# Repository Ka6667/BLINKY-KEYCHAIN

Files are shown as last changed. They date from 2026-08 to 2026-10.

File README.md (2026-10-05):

Add a heading

## Table of Contents
* [What is BLINKY KEYCHAIN?](#what-is-blinky-keychain)
* [Why did I build it?](#why-did-i-build-it)
* [How to use BLINKY](#how-to-use-blinky)
* [How to build BLINKY](#how-to-build-blinky)
* [Schematics](#schematics)
* [PCB Design](#pcb-design)
* [BOM](#bom)

## What is BLINKY KEYCHAIN??
Blinky Keycahin is a custom made PCB that works as a keychain. it's so interactive and it looks really cool with built in modes for the LEDs. it also tells you the time in the OLED display. it's so small and so easy to assymble.

## Why did I build it?
This project is made for a friend. This friend always like to buy matching key chains so I decided to make one for both of us. The process of building was quite simple. I made the schematics using Kicad then I made the PCB. then I made a very simple zine page.

## How to use BLINKY?
the LEDS always keep making these cool patterns and the OLED Display shows the time to make sure that you will not get late to any appointment!

## How to build BLINKY?
1. First install the Gerber files and use JLCPCB to build the PCB.
2. Buy the rest of the components and use a soldering iron to solder everything.
3. Upload the code
4. ENJOY IT!!!!

## Schematics


## PCB Design




## BOM
| Part | Amount | Price | Link |
| :--- | :---: | :---: | :--- |
| XIAO-ESP32C3 | 1 | $3.9 | [Temu Link]([https://temu.com/ul/kuiper/un9.html](https://www.seeedstudio.com/XIAO-RP2040-v1-0-p-5026.html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)) |
| 1000K Ohm resistor | 1 | $0.05 | [Amazon Link](https://www.amazon.eg/-/en/Resistor-1K-ohm-4W-2pcs/dp/B0CJQ3M5J1/) |
| Push-buttons | 1 | $0.04 | [Temu Link](https://www.temu.com/eg-en/10pcs-6x6x5mm--tactile-tact-push-button-micro-switch-mini-micro-momentary-tactile-push-button-switch--x-5mm-g-605681855863393.html) |
| PCB | 1 | $2.00 | [JLCPCB Link](https://cart.jlcpcb.com) |
| LED | 5 | $0.20 | [LED](https://www.ram-e-shop.com/shop/led-pack-jumbo-300-led-pack-jumbo-mixed-300-led-free-storage-box-7525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) |
| LIPO-Battery | 1 | $1.10 | [Makers Electronics Link](https://makerselectronics.com/product/rechargeable-400925-lipo-battery/) |
| **Total** | | **$7.3** <br>*(shipping not included)* | |

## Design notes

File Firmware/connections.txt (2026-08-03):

LED
D0  
D1
D2
D3
D6
-------------------------
OLED
SDA = D4
SCL = D5
-------------------------
Libraries included!!! 
#include <Wire.h>
#include <Adafruit_GFX.h>
#include <Adafruit_SSD1306.h>
#include <RTClib.h>

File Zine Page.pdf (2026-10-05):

# BLINKY KEYCHAIN!

# MORE THAN A NORMAL KEYCHAIN

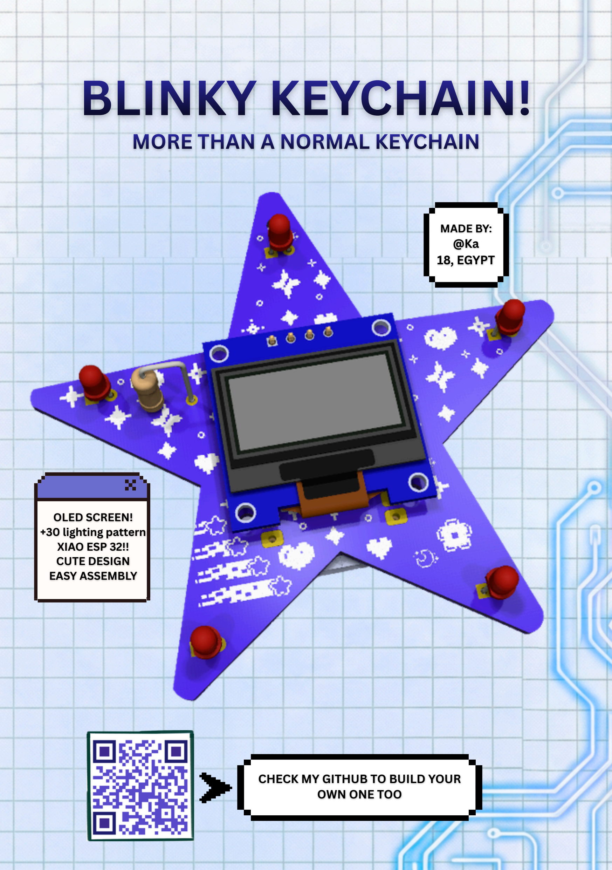
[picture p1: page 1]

CHECK MY GITHUB TO BUILD YOUR OWN ONE TOO

CHECK MY GITHUB TO BUILD YOUR OWN ONE TOO

MADE BY:
@Ka
18, EGYPT

MADE BY:
@Ka
18, EGYPT

OLED SCREEN!
+30 lighting pattern
XIAO ESP 32!!
CUTE DESIGN
EASY ASSEMBLY

OLED SCREEN!
+30 lighting pattern
XIAO ESP 32!!
CUTE DESIGN
EASY ASSEMBLY

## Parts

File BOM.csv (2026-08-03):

Part | Amount | Price | Link
XIAO-ESP32C3 | 1 | $3.90 | https://www.seeedstudio.com/XIAO-RP2040-v1-0-p-5026.html
1000K Ohm resistor | 1 | $0.05 | https://www.amazon.eg/-/en/Resistor-1K-ohm-4W-2pcs/dp/B0CJQ3M5J1/
Push-buttons | 1 | $0.04 | https://www.temu.com/eg-en/10pcs-6x6x5mm--tactile-tact-push-button-micro-switch-mini-micro-momentary-tactile-push-button-switch--x-5mm-g-605681855863393.html
PCB | 1 | $2.00 | https://cart.jlcpcb.com
LED | 5 | $0.20 | https://www.ram-e-shop.com/shop/led-pack-jumbo-300-led-pack-jumbo-mixed-300-led-free-storage-box-7525
LIPO-Battery | 1 | $1.10 | https://makerselectronics.com/product/rechargeable-400925-lipo-battery/
Total |  | $7.30 (shipping not included)

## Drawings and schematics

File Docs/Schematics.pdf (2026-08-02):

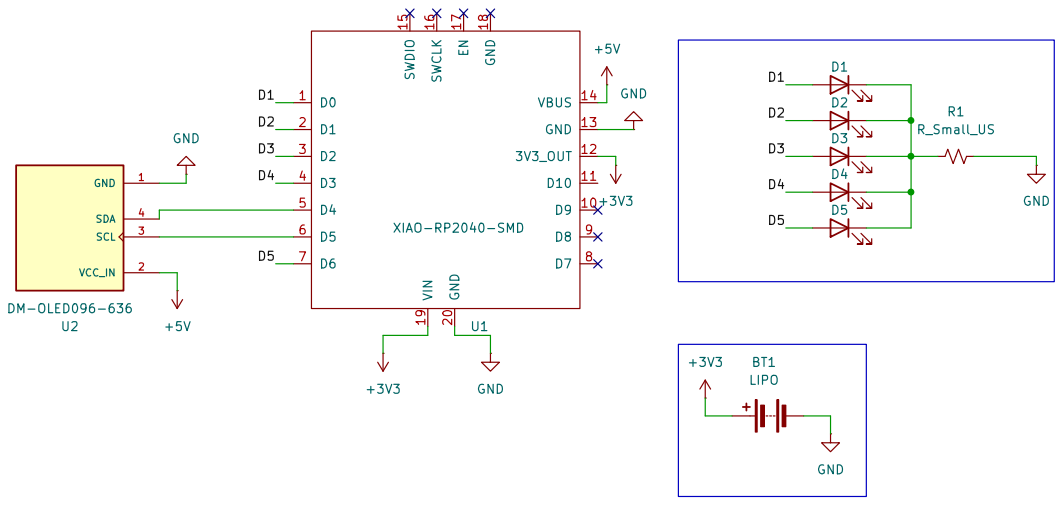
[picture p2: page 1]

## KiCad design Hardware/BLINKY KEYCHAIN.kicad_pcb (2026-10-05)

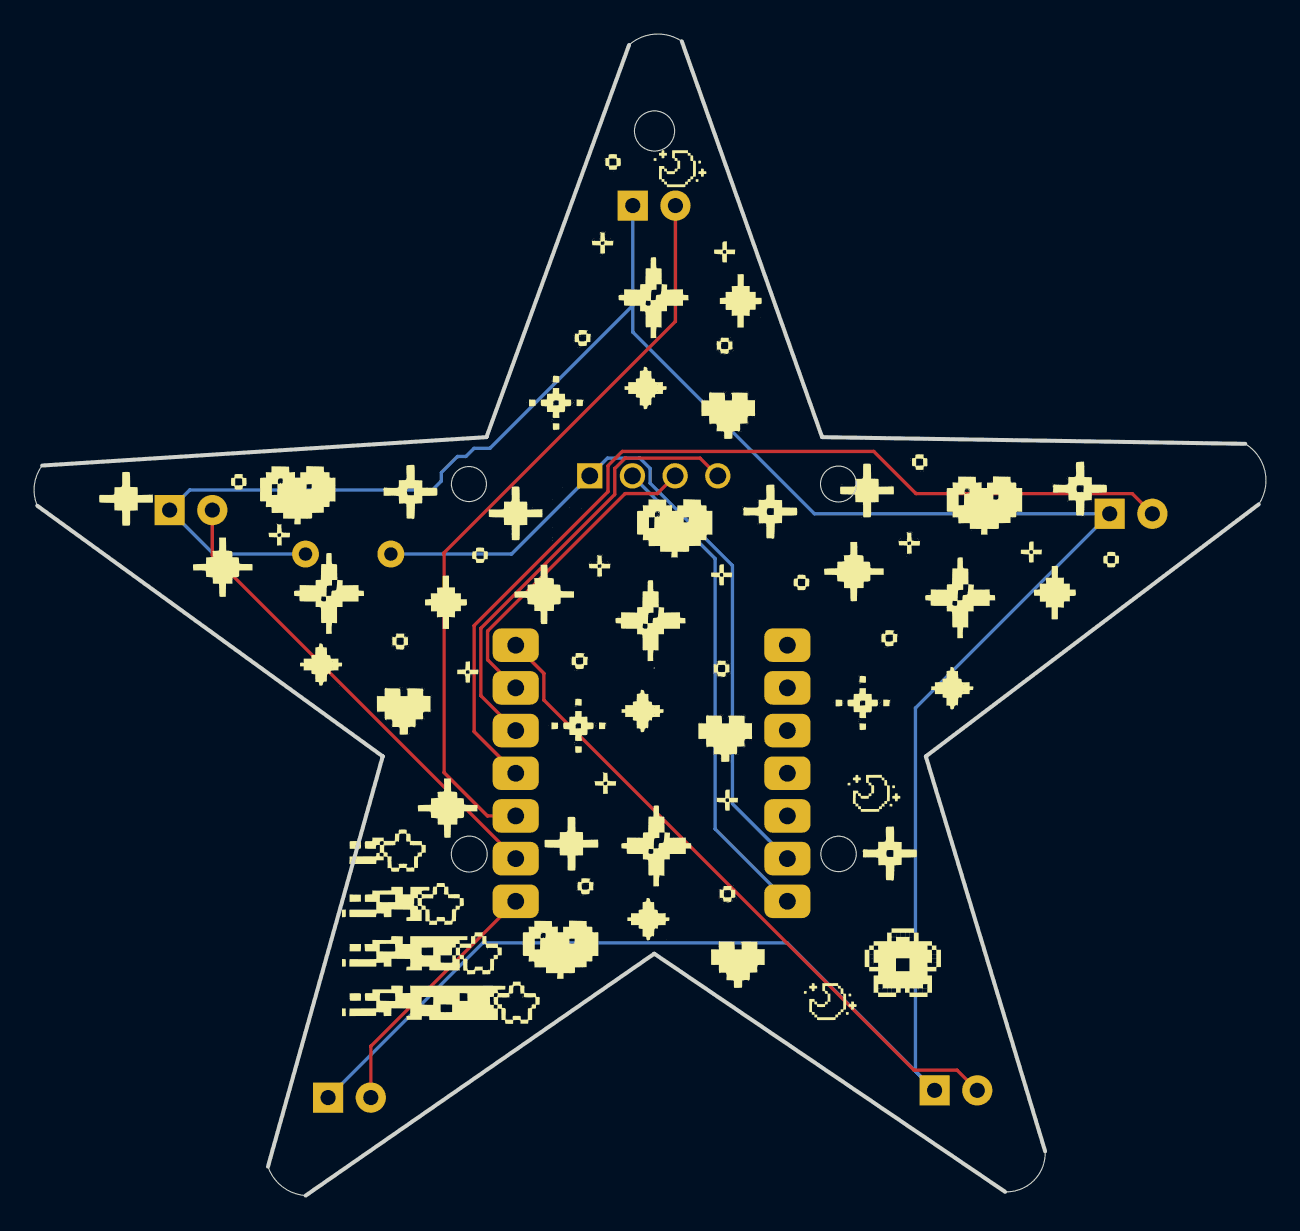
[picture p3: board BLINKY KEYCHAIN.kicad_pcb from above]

Board: 2 copper layers, 73.3 x 69.1 mm, 8 parts (1 on the bottom side), 11 nets.

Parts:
D1, D2, D3, D4, D5: LED; LED_D3.0mm
R1: R_Small_US; R_Axial_DIN0309_L9.0mm_D3.2mm_P5.08mm_Vertical
U1: XIAO-RP2040-SMD
U2: DM-OLED096-636; MODULE_DM-OLED096-636

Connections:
+3V3: U1.12 (3V3_OUT), U1.19 (VIN)
+5V: U1.14 (VBUS), U2.2 (VCC_IN)
/D1: D1.2 (A), U1.1 (D0)
/D2: D2.2 (A), U1.2 (D1)
/D3: D3.2 (A), U1.3 (D2)
/D4: D4.2 (A), U1.4 (D3)
/D5: D5.2 (A), U1.7 (D6)
GND: R1.2, U1.13 (GND), U1.20 (GND), U2.1 (GND)
unnamed: D1.1 (K), D2.1 (K), D3.1 (K), D4.1 (K), D5.1 (K), R1.1
unnamed: U1.5 (D4), U2.4 (SDA)
unnamed: U1.6 (D5), U2.3 (SCL)

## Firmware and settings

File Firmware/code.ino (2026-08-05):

#include <Wire.h>
#include <Adafruit_GFX.h>
#include <Adafruit_SSD1306.h>
#include <RTClib.h>

// ---- OLED Display config ----
#define SCREEN_WIDTH   128
#define SCREEN_HEIGHT  64
#define OLED_RESET     -1
#define SCREEN_ADDRESS 0x3C

// ---- I2C pins (XIAO RP2040) ----
#define I2C_SDA 4
#define I2C_SCL 5

// ---- LED pins ----
#define LED1 0
#define LED2 1
#define LED3 2
#define LED4 3
#define LED5 6

Adafruit_SSD1306 display(SCREEN_WIDTH, SCREEN_HEIGHT, &Wire, OLED_RESET);
RTC_DS3231 rtc;

void setup() {
  Serial.begin(115200);

  // LEDs
  pinMode(LED1, OUTPUT);
  pinMode(LED2, OUTPUT);
  pinMode(LED3, OUTPUT);
  pinMode(LED4, OUTPUT);
  pinMode(LED5, OUTPUT);

  // I2C on custom pins, then bring it up once
  Wire.setSDA(I2C_SDA);
  Wire.setSCL(I2C_SCL);
  Wire.begin();

  if (!display.begin(SSD1306_SWITCHCAPVCC, SCREEN_ADDRESS)) {
    Serial.println(F("SSD1306 allocation failed"));
    for (;;); // halt here only, doesn't block the rest of setup
  }
  display.clearDisplay();
  display.display();

  // Initialize RTC
  if (!rtc.begin()) {
    Serial.println("Couldn't find RTC");
    while (1);
  }

  // Automatically set RTC to compile time if it lost power
  if (rtc.lostPower()) {
    rtc.adjust(DateTime(F(__DATE__), F(__TIME__)));
  }
}

void blink() {
  digitalWrite(LED1, HIGH);
  delay(500);
  digitalWrite(LED2, HIGH);
  delay(500);
  digitalWrite(LED3, HIGH);
  delay(500);
  digitalWrite(LED4, HIGH);   // was LED1 again — fixed
  delay(500);
  digitalWrite(LED5, HIGH);
  delay(500);
  digitalWrite(LED1, LOW);
  delay(500);
  digitalWrite(LED2, LOW);
  delay(500);
  digitalWrite(LED3, LOW);
  delay(500);
  digitalWrite(LED4, LOW);
  delay(500);
  digitalWrite(LED5, LOW);
  delay(500);
}

void allblink() {
  digitalWrite(LED1, HIGH);
  digitalWrite(LED2, HIGH);
  digitalWrite(LED3, HIGH);
  digitalWrite(LED4, HIGH);
  digitalWrite(LED5, HIGH);
  delay(200);
  digitalWrite(LED1, LOW);
  digitalWrite(LED2, LOW);
  digitalWrite(LED3, LOW);
  digitalWrite(LED4, LOW);
  digitalWrite(LED5, LOW);
  delay(200);
}

// Renamed from random() — that name collides with Arduino's built-in RNG
void randomLED() {
  int pins[] = {LED1, LED2, LED3, LED4, LED5};
  int pin = pins[random(0, 5)]; // random(min, max) is exclusive of max, so 0..4 covers all 5
  digitalWrite(pin, HIGH);
  delay(200);
  digitalWrite(pin, LOW);
}

void screen() {
  DateTime now = rtc.now();

  display.clearDisplay();

  // Display Date
  display.setTextSize(1);
  display.setTextColor(SSD1306_WHITE);
  display.setCursor(15, 10);
  display.print(now.year(), DEC);
  display.print('/');
  display.print(now.month(), DEC);
  display.print('/');
  display.print(now.day(), DEC);

  // Display Time
  display.setTextSize(2);
  display.setCursor(15, 30);

  if (now.hour() < 10) display.print('0');
  display.print(now.hour(), DEC);
  display.print(':');

  if (now.minute() < 10) display.print('0');
  display.print(now.minute(), DEC);
  display.print(':');

  if (now.second() < 10) display.print('0');
  display.print(now.second(), DEC);

  display.display();
  delay(1000);
}

void loop() {
  screen();
  blink();
  allblink();
  randomLED();
}
